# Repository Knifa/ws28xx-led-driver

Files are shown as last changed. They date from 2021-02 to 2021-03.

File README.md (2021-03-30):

# ws28xx-led-driver

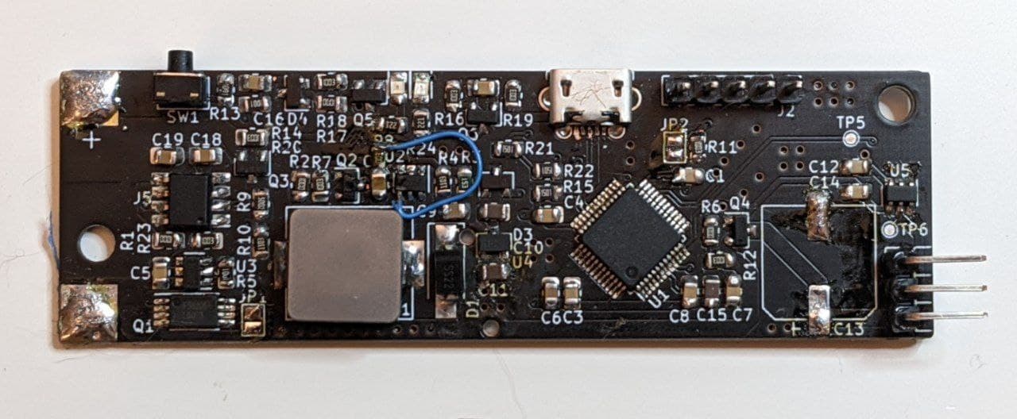
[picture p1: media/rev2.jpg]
Rev 2


This is a straightforward DIY WS28xx LED driver. It's got these features:

- STM32F103C8T6 used as the microcontroller.
- Intended to be powered by a single-cell Li-ion battery, with USB charging and
  cell protection.
- 5V 1.5Aish step-up for LED power.
- Single button for soft-power and settings.
- 0805 SMD components or thereabouts.

## License

- Firmware under [MIT License](./firmware/LICENSE.md).
- Hardware under [CC-BY-SA-4.0](./hardware/LICENSE.md).

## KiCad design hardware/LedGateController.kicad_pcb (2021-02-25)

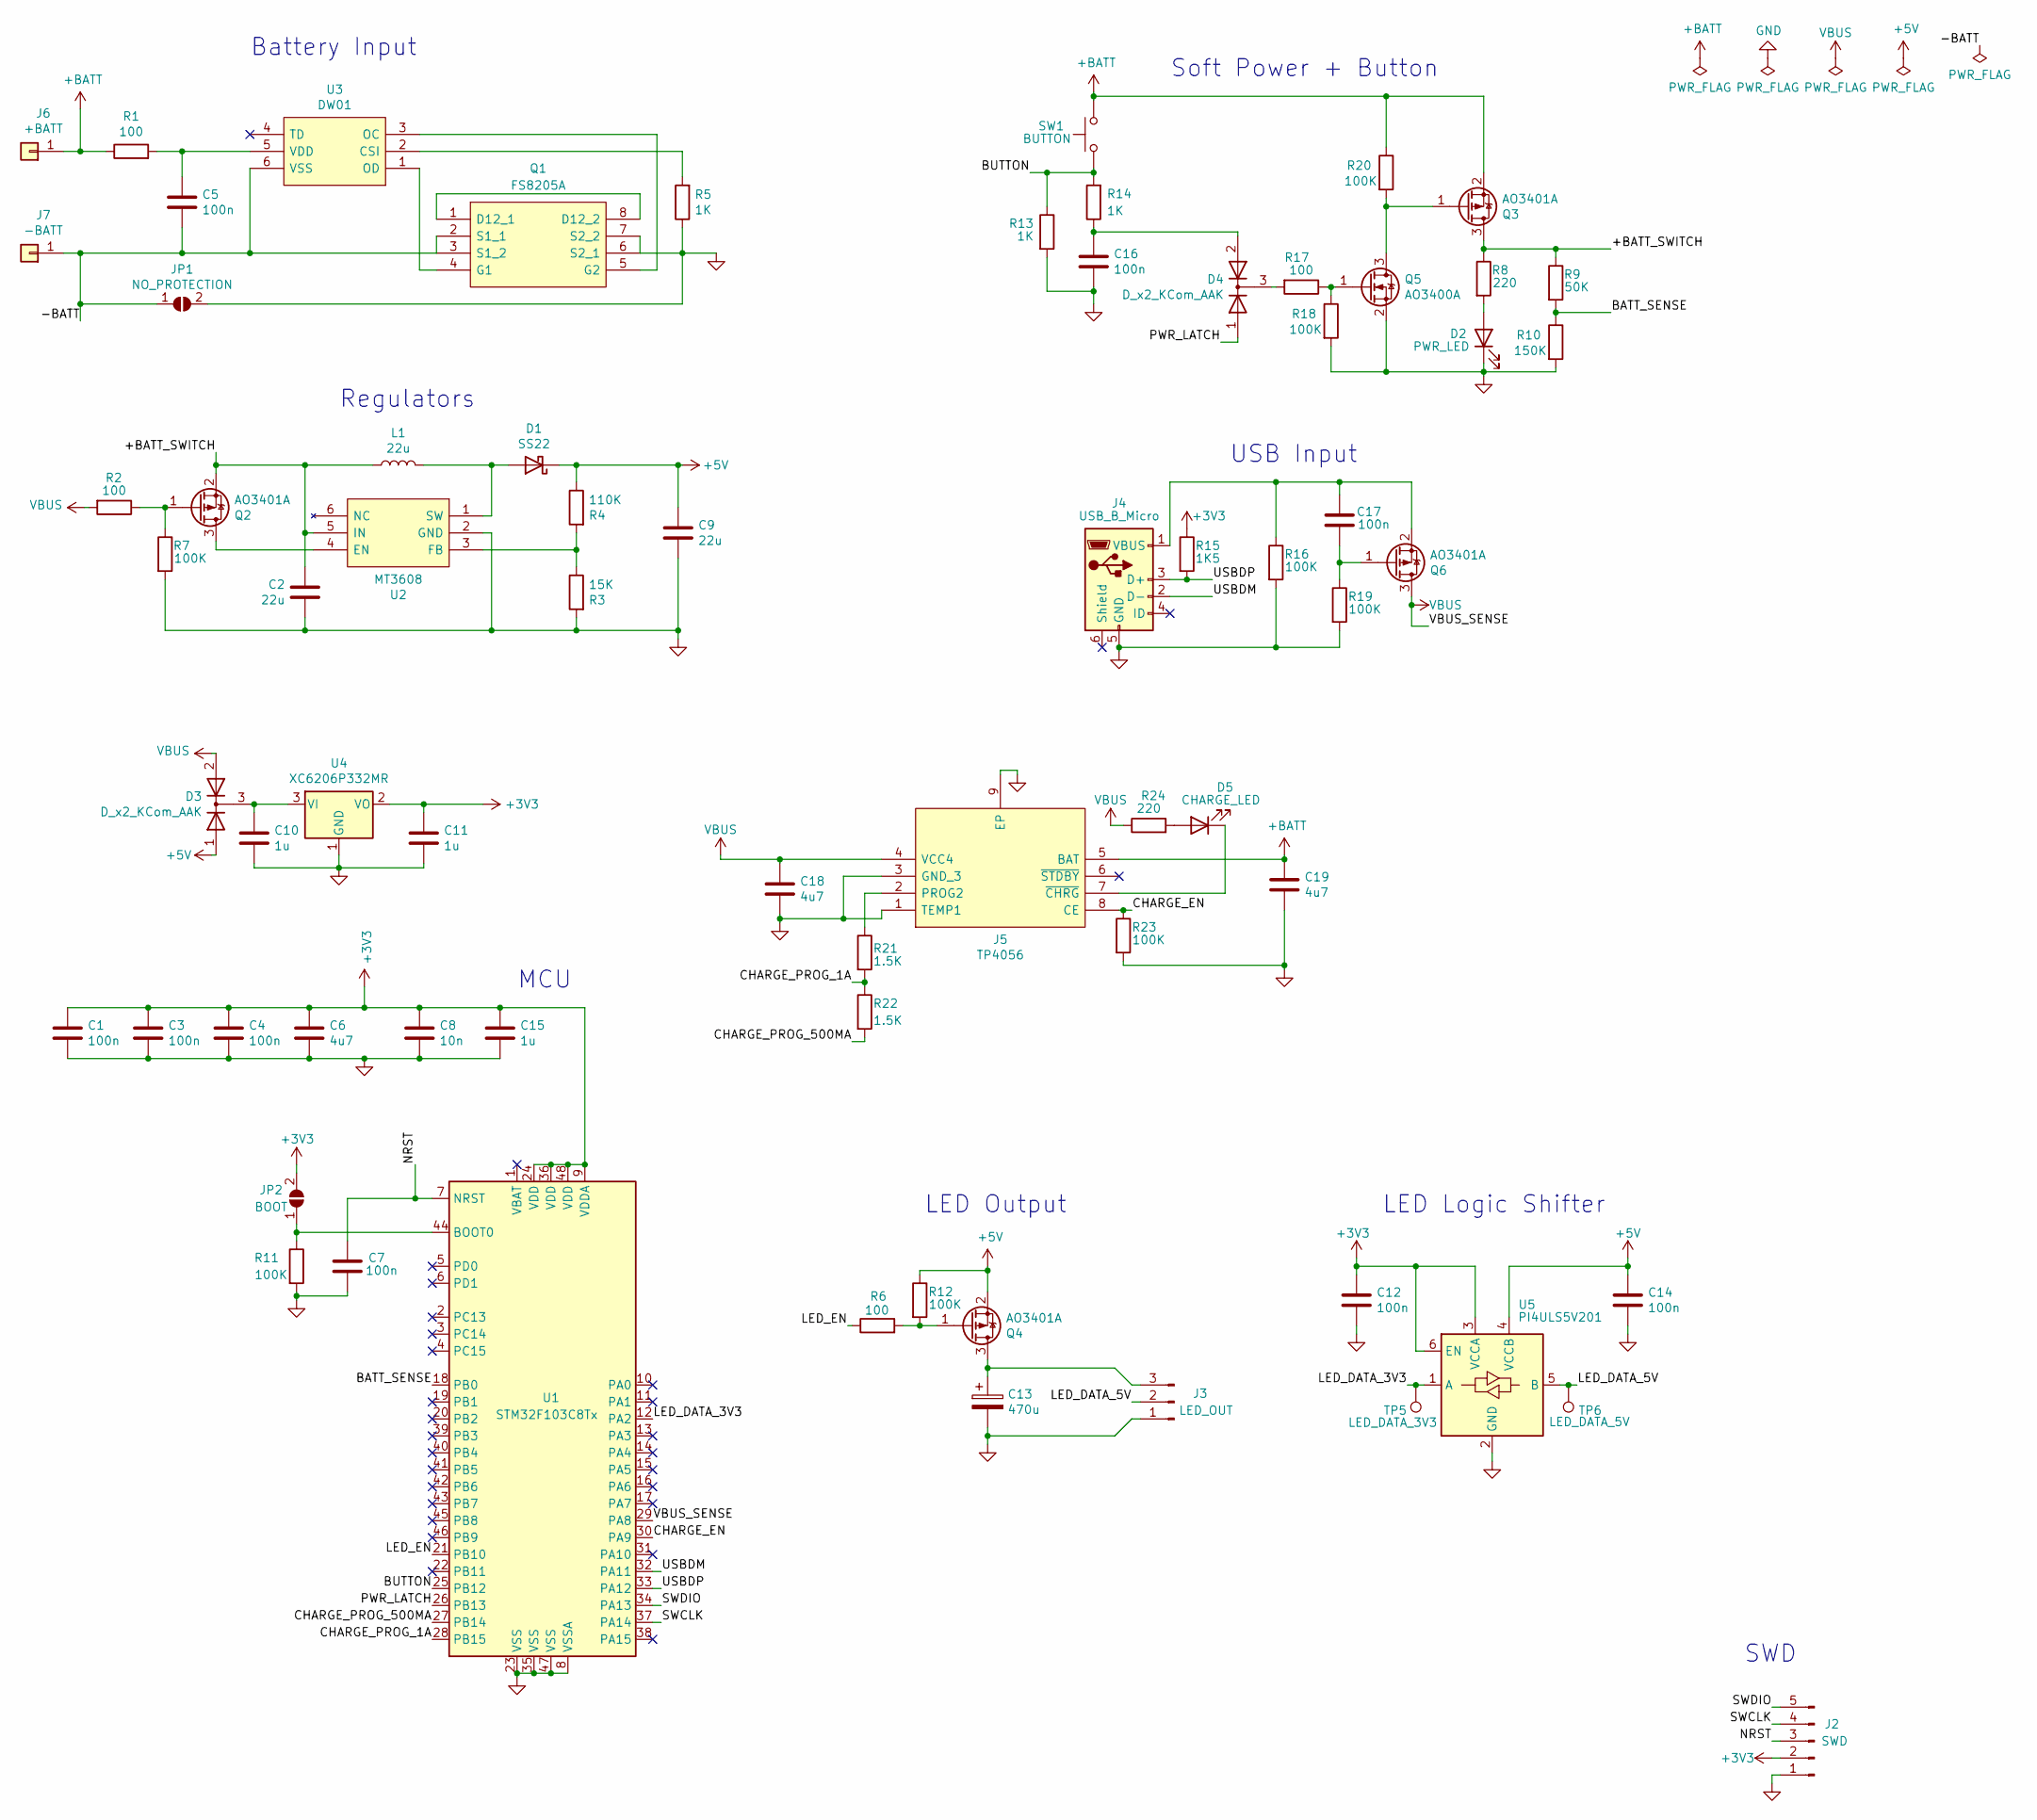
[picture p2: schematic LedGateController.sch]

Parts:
C1, C3, C4, C5, C7, C12, C14, C16, C17: 100n; C_0805_2012Metric
C2, C9: 22u; C_0805_2012Metric
C6, C18, C19: 4u7; C_0805_2012Metric
C8: 10n; C_0805_2012Metric
C10, C11, C15: 1u; C_0805_2012Metric
C13: 470u; CP_Elec_10x7.7
D1: SS22; D_SMA_Handsoldering
D2: PWR_LED; LED_0805_2012Metric
D3, D4: D_x2_KCom_AAK; SOT-23
D5: CHARGE_LED; LED_0805_2012Metric
J2: SWD; PinHeader_1x05_P2.54mm_Vertical
J3: LED_OUT; PinHeader_1x03_P2.54mm_Horizontal
J4: USB_B_Micro; U254051T4BHJ25S2S
J5: TP4056; SOIC127P600X175-9N; Manufacturer_Part_Number TP4056
J6: +BATT; Battery Pad
J7: -BATT; Battery Pad
JP1: NO_PROTECTION; SolderJumper-2_P1.3mm_Open_Pad1.0x1.5mm
JP2: BOOT; SolderJumper-2_P1.3mm_Open_Pad1.0x1.5mm
L1: 22u; YT1040-220M
Q1: FS8205A; TSSOP-8_4.4x3mm_P0.65mm; Manufacturer_Part_Number FS8205A
Q2, Q3, Q4, Q6: AO3401A; SOT-23
Q5: AO3400A; SOT-23
R1, R2, R6, R17: 100; R_0805_2012Metric
R3: 15K; R_0805_2012Metric
R4: 110K; R_0805_2012Metric
R5, R13, R14: 1K; R_0805_2012Metric
R7, R11, R12, R16, R18, R19, R20, R23: 100K; R_0805_2012Metric
R8, R24: 220; R_0805_2012Metric
R9: 50K; R_0805_2012Metric
R10: 150K; R_0805_2012Metric
R15: 1K5; R_0805_2012Metric
R21, R22: 1.5K; R_0805_2012Metric
SW1: BUTTON; TS-1009B-04326
TP5: LED_DATA_3V3; TestPoint_Pad_D1.0mm
TP6: LED_DATA_5V; TestPoint_Pad_D1.0mm
U1: STM32F103C8Tx; LQFP-48_7x7mm_P0.5mm
U2: MT3608; SOT-23-6; Manufacturer_Part_Number MT3608
U3: DW01; SOT-23-6; Manufacturer_Part_Number DW01
U4: XC6206P332MR; SOT-23
U5: PI4ULS5V201; SOT-23-6

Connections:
+3V3: C1.1, C3.1, C4.1, C6.1, C8.1, C11.1, C12.1, C15.1, J2.2, JP2.2 (B), R15.1, U1.9 (VDDA), U1.24 (VDD), U1.36 (VDD), U1.48 (VDD), U4.2 (VO), U5.3 (VCCA), U5.6 (EN)
+5V: C9.1, C14.1, D1.1 (K), D3.1 (A), Q4.2 (S), R4.1, R12.1, U5.4 (VCCB)
+BATT: C19.1, J5.5 (BAT), J6.1, Q3.2 (S), R1.1, R20.1, SW1.2; also elsewhere on the board
/+BATT_SWITCH: C2.1, L1.1, Q2.2 (S), Q3.3 (D), R8.1, R9.1, U2.5 (IN)
/-BATT: C5.2, J7.1, JP1.1 (A), Q1.2 (S1_1), Q1.3 (S1_2), U3.6 (VSS)
/BATT_SENSE: R9.2, R10.1, U1.18 (PB0)
/BUTTON: R13.1, R14.2, SW1.1, U1.25 (PB12)
/CHARGE_EN: J5.8 (CE), R23.1, U1.30 (PA9)
/CHARGE_PROG_1A: R21.2, R22.1, U1.28 (PB15)
/CHARGE_PROG_500MA: R22.2, U1.27 (PB14)
/LED_DATA_3V3: TP5.1, U1.12 (PA2), U5.1 (A)
/LED_DATA_5V: J3.2, TP6.1, U5.5 (B)
/LED_EN: R6.1, U1.21 (PB10)
/NRST: C7.2, J2.3, U1.7 (NRST)
/PWR_LATCH: D4.1 (A), U1.26 (PB13)
/SWCLK: J2.4, U1.37 (PA14)
/SWDIO: J2.5, U1.34 (PA13)
/USBDM: J4.2 (D-), U1.32 (PA11)
/USBDP: J4.3 (D+), R15.2, U1.33 (PA12)
GND: C1.2, C2.2, C3.2, C4.2, C6.2, C7.1, C8.2, C9.2, C10.2, C11.2, C12.2, C13.2, C14.2, C15.2, C16.2, C18.2, C19.2, D2.1 (K), J2.1, J3.1, J4.5 (GND), J5.1 (TEMP1), J5.3 (GND_3), J5.9 (EP), JP1.2 (B), Q1.6 (S2_1), Q1.7 (S2_2), Q5.2 (S), R3.2, R5.1, R7.2, R10.2, R11.2, R13.2, R16.2, R18.2, R19.2, R23.2, U1.8 (VSSA), U1.23 (VSS), U1.35 (VSS), U1.47 (VSS), U2.2 (GND), U4.1 (GND), U5.2 (GND)
unnamed: C5.1, R1.2, U3.5 (VDD)
unnamed: C10.1, D3.3 (K), U4.3 (VI)
unnamed: C13.1, J3.3, Q4.3 (D)
unnamed: C16.1, D4.2 (A), R14.1
unnamed: C17.1, J4.1 (VBUS), Q6.2 (S), R16.1
unnamed: C17.2, Q6.1 (G), R19.1
unnamed: D1.2 (A), L1.2, U2.1 (SW)
unnamed: D2.2 (A), R8.2
unnamed: D4.3 (K), R17.2
unnamed: D5.1 (K), J5.7 (~CHRG)
unnamed: D5.2 (A), R24.2
unnamed: J5.2 (PROG2), R21.1
unnamed: JP2.1 (A), R11.1, U1.44 (BOOT0)
unnamed: Q1.1 (D12_1), Q1.8 (D12_2)
unnamed: Q1.4 (G1), U3.1 (OD)
unnamed: Q1.5 (G2), U3.3 (OC)
unnamed: Q2.1 (G), R2.1, R7.1
unnamed: Q2.3 (D), U2.4 (EN)
unnamed: Q3.1 (G), Q5.3 (D), R20.2
unnamed: Q4.1 (G), R6.2, R12.2
unnamed: Q5.1 (G), R17.1, R18.1
unnamed: R3.1, R4.2, U2.3 (FB)
unnamed: R5.2, U3.2 (CSI)
VBUS: C18.1, D3.2 (A), J5.4 (VCC4), Q6.3 (D), R2.2, R24.1, U1.29 (PA8)

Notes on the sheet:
Regulators
MCU
SWD
Battery Input
LED Output
LED Logic Shifter
Soft Power + Button
USB Input

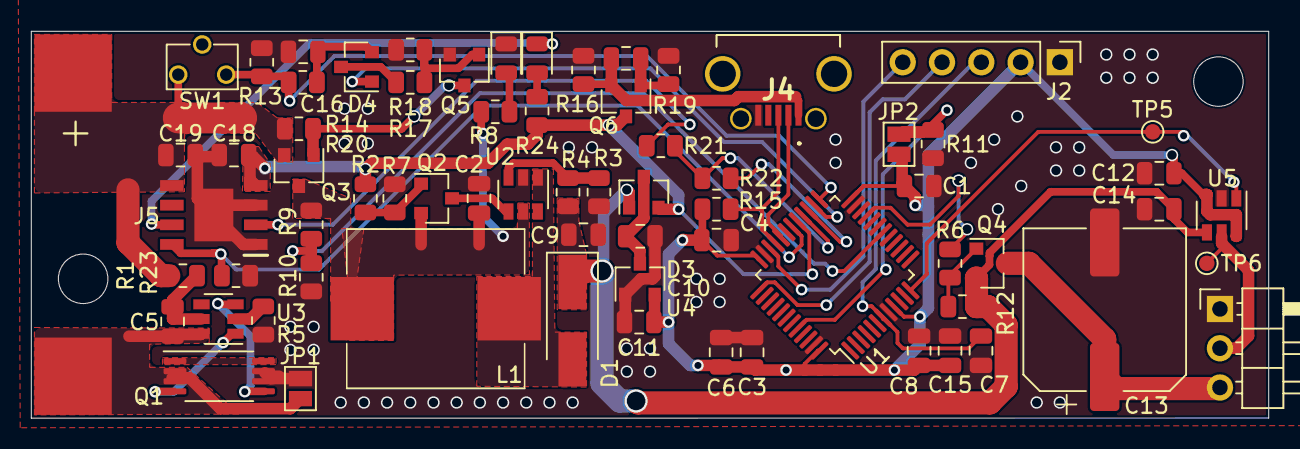
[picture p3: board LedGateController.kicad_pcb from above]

Board: 2 copper layers, 80.0 x 25.0 mm, 71 parts (0 on the bottom side), 44 nets.

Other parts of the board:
+: +BATT; Battery Pad

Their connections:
+BATT: +.1; also elsewhere on the board

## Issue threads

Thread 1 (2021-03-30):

Rev. 3 Oopsies

Knifa, 2021-03-30:
Uh oh!

- [ ] MT3608 EN needs pull-down.
- [ ] LED 5V cap needs inrush limit.
- [ ] LED 5V cap could be smaller.
- [ ] MCU needs external oscillator to reach 72MHz and stable USB.

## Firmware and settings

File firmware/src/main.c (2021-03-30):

#include "pwr.h"
#include "button.h"
#include "led.h"
#include "mode.h"
#include "stm32f1xx_ll_bus.h"
#include "stm32f1xx_ll_cortex.h"
#include "stm32f1xx_ll_dma.h"
#include "stm32f1xx_ll_exti.h"
#include "stm32f1xx_ll_gpio.h"
#include "stm32f1xx_ll_pwr.h"
#include "stm32f1xx_ll_rcc.h"
#include "stm32f1xx_ll_system.h"
#include "stm32f1xx_ll_tim.h"
#include "stm32f1xx_ll_utils.h"
#include "time.h"

#define BATTERY_CHECK_MS 5000
#define DRAW_MS (1000 / 60)

static void init_clocks();
static void check_battery();

int main()
{
  init_clocks();

  pwr_init();

  if (pwr_is_vbus_present())
  {
    pwr_shutdown();
    pwr_set_chg_enable(1);
    while (1)
    {
    }
  }

  button_init();
  led_init();

  led_set_power(1);
  check_battery();

  NVIC_SetPriority(SysTick_IRQn, 255);
  NVIC_EnableIRQ(SysTick_IRQn);
  LL_SYSTICK_EnableIT();

  while (1)
  {
  }
}

void init_clocks()
{
  LL_FLASH_SetLatency(LL_FLASH_LATENCY_1);

  LL_RCC_HSI_Enable();
  while (LL_RCC_HSI_IsReady() != 1)
  {
  };

  LL_RCC_PLL_ConfigDomain_SYS(LL_RCC_PLLSOURCE_HSI_DIV_2, LL_RCC_PLL_MUL_12);
  LL_RCC_PLL_Enable();
  while (LL_RCC_PLL_IsReady() != 1)
  {
  };

  LL_RCC_SetAHBPrescaler(LL_RCC_SYSCLK_DIV_1);
  LL_RCC_SetAPB1Prescaler(LL_RCC_APB1_DIV_2);
  LL_RCC_SetAPB2Prescaler(LL_RCC_APB2_DIV_1);
  LL_RCC_SetADCClockSource(LL_RCC_ADC_CLKSRC_PCLK2_DIV_4);

  LL_RCC_SetSysClkSource(LL_RCC_SYS_CLKSOURCE_PLL);
  while (LL_RCC_GetSysClkSource() != LL_RCC_SYS_CLKSOURCE_STATUS_PLL)
  {
  };

  LL_SetSystemCoreClock(48000000);
  LL_Init1msTick(48000000);

  LL_AHB1_GRP1_EnableClock(LL_AHB1_GRP1_PERIPH_DMA1);

  LL_APB1_GRP1_EnableClock(LL_APB1_GRP1_PERIPH_TIM2);
  LL_APB1_GRP1_EnableClock(LL_APB1_GRP1_PERIPH_TIM3);

  LL_APB2_GRP1_EnableClock(LL_APB2_GRP1_PERIPH_GPIOA);
  LL_APB2_GRP1_EnableClock(LL_APB2_GRP1_PERIPH_GPIOB);
  LL_APB2_GRP1_EnableClock(LL_APB2_GRP1_PERIPH_ADC1);
  LL_APB2_GRP1_EnableClock(LL_APB2_GRP1_PERIPH_ADC2);
}

void check_battery()
{
  uint32_t bat = pwr_get_bat_voltage();
  if (led_get_power())
  {
    if (bat < PWR_BAT_OFF_THRESHOLD)
    {
      led_set_power(0);
    }
  }
  else
  {
    if (bat >= PWR_BAT_ON_THRESHOLD)
    {
      led_set_power(1);
    }
  }
}

void SysTick_Handler()
{
  time_systick_handler();

  if (time_millis() % BATTERY_CHECK_MS == 0)
  {
    check_battery();
  }

  if (time_millis() % DRAW_MS == 0)
  {
    mode_update();
    led_update();
  }
}

void button_handler(ButtonEvent *event)
{
  static Mode last_mode;

  switch (event->type)
  {
  case (BUTTON_EVENT_HELD):
    last_mode = mode;
    mode = MODE_BATTERY;
    break;

  case (BUTTON_EVENT_HELD_RELEASE):
    mode = last_mode;
    break;

  case (BUTTON_EVENT_PRESSES):
    switch (event->presses)
    {
    case 1:
      color_i = (color_i + 1) % COLORS_LEN;
      break;

    case 2:
      mode = (mode + 1) % MODE_BATTERY;
      break;

    case 3:
      led_set_brightness((led_get_brightness() + 1) % LED_BRIGHTNESS_MAX);
      break;
    }
    break;
  }
}

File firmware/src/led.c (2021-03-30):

#include "led.h"

#include <stm32f1xx_ll_dma.h>
#include <stm32f1xx_ll_gpio.h>
#include <stm32f1xx_ll_tim.h>

#define POWER_PIN LL_GPIO_PIN_10
#define DATA_PIN LL_GPIO_PIN_2

#define LED_BPP 24

#define ARR_TX 59

#define CCR_US_PERIOD 125
#define CCR_US_0 40
#define CCR_US_1 80

#define CCR_0 (ARR_TX * CCR_US_0 / CCR_US_PERIOD)
#define CCR_1 (ARR_TX * CCR_US_1 / CCR_US_PERIOD)
#define CCR_RESET 0

#define CCR_BUFFER_LEDS_HALF 8
#define CCR_BUFFER_LEDS (CCR_BUFFER_LEDS_HALF * 2)

#define CCR_BUFFER_LEN (CCR_BUFFER_LEDS * LED_BPP)

static uint32_t rgb_buf[LED_COUNT];
static uint32_t *rgb = rgb_buf;

static uint32_t rgb_led_buf[LED_COUNT];
static uint32_t *rgb_led = rgb_led_buf;

static uint32_t rgb_offset = 0;
static uint8_t ccr_buffer[CCR_BUFFER_LEN];

static uint8_t brightness_i = 3;
static uint8_t is_powered = 0;
static uint8_t is_transmitting = 0;

static uint8_t apply_brightness(uint8_t v);
static uint8_t apply_gamma(uint8_t v);
static void fill_ccr_buffer(uint32_t ccr_led_offset, uint32_t ccr_led_count);
static void handle_dma();

void led_init()
{
  LL_GPIO_InitTypeDef gpio_init = {0};
  LL_TIM_InitTypeDef tim_init = {0};
  LL_TIM_OC_InitTypeDef tim_oc_init = {0};

  tim_init.Prescaler = 0;
  tim_init.CounterMode = LL_TIM_COUNTERMODE_UP;
  tim_init.Autoreload = ARR_TX;
  tim_init.RepetitionCounter = 0;

  LL_TIM_Init(TIM2, &tim_init);
  LL_TIM_EnableAllOutputs(TIM2);
  LL_TIM_EnableDMAReq_CC3(TIM2);

  tim_oc_init.OCMode = LL_TIM_OCMODE_PWM1;
  tim_oc_init.OCState = LL_TIM_OCSTATE_ENABLE;
  tim_oc_init.CompareValue = 0;

  LL_TIM_OC_Init(TIM2, LL_TIM_CHANNEL_CH3, &tim_oc_init);
  LL_TIM_OC_EnablePreload(TIM2, LL_TIM_CHANNEL_CH3);

  LL_DMA_SetPeriphAddress(DMA1, LL_DMA_CHANNEL_1, (uint32_t)&TIM2->CCR3);
  LL_DMA_SetChannelPriorityLevel(DMA1, LL_DMA_CHANNEL_1,
                                 LL_DMA_PRIORITY_VERYHIGH);
  LL_DMA_SetDataTransferDirection(DMA1, LL_DMA_CHANNEL_1,
                                  LL_DMA_DIRECTION_MEMORY_TO_PERIPH);
  LL_DMA_SetPeriphIncMode(DMA1, LL_DMA_CHANNEL_1, LL_DMA_PERIPH_NOINCREMENT);
  LL_DMA_SetMemoryIncMode(DMA1, LL_DMA_CHANNEL_1, LL_DMA_MEMORY_INCREMENT);
  LL_DMA_SetPeriphSize(DMA1, LL_DMA_CHANNEL_1, LL_DMA_PDATAALIGN_HALFWORD);
  LL_DMA_SetMemorySize(DMA1, LL_DMA_CHANNEL_1, LL_DMA_MDATAALIGN_BYTE);
  LL_DMA_EnableIT_TC(DMA1, LL_DMA_CHANNEL_1);
  LL_DMA_EnableIT_HT(DMA1, LL_DMA_CHANNEL_1);

  NVIC_SetPriority(DMA1_Channel1_IRQn, 0);
  NVIC_EnableIRQ(DMA1_Channel1_IRQn);

  // LED data
  gpio_init.Pin = DATA_PIN;
  gpio_init.Mode = LL_GPIO_MODE_ALTERNATE;
  gpio_init.Speed = LL_GPIO_SPEED_FREQ_HIGH;
  gpio_init.OutputType = LL_GPIO_OUTPUT_PUSHPULL;

  LL_GPIO_Init(GPIOA, &gpio_init);

  // LED power
  gpio_init.Pin = POWER_PIN;
  gpio_init.Mode = LL_GPIO_MODE_OUTPUT;
  gpio_init.Speed = LL_GPIO_SPEED_FREQ_LOW;
  gpio_init.OutputType = LL_GPIO_OUTPUT_OPENDRAIN;

  LL_GPIO_Init(GPIOB, &gpio_init);
  LL_GPIO_SetOutputPin(GPIOB, POWER_PIN);
}

void led_update()
{
  if (!is_powered)
  {
    return;
  }

  while (is_transmitting)
  {
  }
  is_transmitting = 1;

  for (uint8_t i = 0; i < LED_COUNT; i++)
  {
    uint32_t v = rgb[i];
    uint8_t r = RGB_R(v);
    uint8_t g = RGB_G(v);
    uint8_t b = RGB_B(v);

    r = apply_gamma(r);
    r = apply_brightness(r);

    g = apply_gamma(g);
    g = apply_brightness(g);

    b = apply_gamma(b);
    b = apply_brightness(b);

    rgb_led[i] = RGB_UINT(r, g, b);
  }

  rgb_offset = 0;
  fill_ccr_buffer(0, CCR_BUFFER_LEDS);
  rgb_offset += CCR_BUFFER_LEDS;

  LL_DMA_DisableChannel(DMA1, LL_DMA_CHANNEL_1);
  LL_DMA_SetMemoryAddress(DMA1, LL_DMA_CHANNEL_1, (uint32_t)ccr_buffer);
  LL_DMA_SetDataLength(DMA1, LL_DMA_CHANNEL_1, CCR_BUFFER_LEN);
  LL_DMA_SetMode(DMA1, LL_DMA_CHANNEL_1, LL_DMA_MODE_CIRCULAR);
  LL_DMA_EnableChannel(DMA1, LL_DMA_CHANNEL_1);

  LL_TIM_EnableCounter(TIM2);
}

uint8_t led_get_power() { return is_powered; }
uint8_t led_get_brightness() { return brightness_i; }

uint32_t led_get(uint16_t i) { return rgb[i]; }

void led_set(uint16_t i, uint32_t v) { rgb[i] = v; }

void led_set_rgb(uint16_t i, uint32_t r, uint32_t g, uint32_t b)
{
  if (i < 0 || i >= LED_COUNT)
  {
    return;
  }

  if (r < 0)
    r = 0;
  if (g < 0)
    g = 0;
  if (b < 0)
    b = 0;

  if (r > 255)
    r = 255;
  if (g > 255)
    g = 255;
  if (b > 255)
    b = 255;

  led_set(i, RGB_UINT(r, g, b));
}

void led_set_rgbf(uint16_t i, float r, float g, float b)
{
  if (r < 0)
    r = 0;
  if (g < 0)
    g = 0;
  if (b < 0)
    b = 0;

  if (r > 1)
    r = 1;
  if (g > 1)
    g = 1;
  if (b > 1)
    b = 1;

  led_set_rgb(i, r * 255, g * 255, b * 255);
}

void led_clear()
{
  for (uint32_t i = 0; i < LED_COUNT; i++)
  {
    led_set(i, 0);
  }
}

void led_set_brightness(uint8_t brightness)
{
  if (brightness < 0)
    brightness = 0;
  if (brightness > LED_BRIGHTNESS_MAX - 1)
    brightness = LED_BRIGHTNESS_MAX - 1;

  brightness_i = brightness;
}

void led_set_power(uint8_t state)
{
  if (state)
  {
    LL_GPIO_ResetOutputPin(GPIOB, POWER_PIN);
  }
  else
  {
    led_clear();
    led_update();

    LL_GPIO_SetOutputPin(GPIOB, POWER_PIN);
  }

  is_powered = state;
}

static uint8_t apply_brightness(uint8_t v)
{
  static uint8_t brightness_table[LED_BRIGHTNESS_MAX] = {50, 25, 12};

  return (uint16_t)v *
         brightness_table[(LED_BRIGHTNESS_MAX - 1) - brightness_i] / 255;
}

static uint8_t apply_gamma(uint8_t v)
{
  static uint8_t gamma_table[256] = {
      0, 0, 0, 0, 0, 0, 0, 0, 0, 0, 0, 0, 0, 0, 0,
      0, 0, 0, 0, 0, 0, 1, 1, 1, 1, 1, 1, 1, 1, 2,
      2, 2, 2, 2, 3, 3, 3, 3, 3, 4, 4, 4, 4, 5, 5,
      5, 5, 6, 6, 6, 7, 7, 7, 8, 8, 8, 9, 9, 9, 10,
      10, 10, 11, 11, 12, 12, 13, 13, 13, 14, 14, 15, 15, 16, 16,
      17, 17, 18, 18, 19, 19, 20, 21, 21, 22, 22, 23, 23, 24, 25,
      25, 26, 27, 27, 28, 29, 29, 30, 31, 31, 32, 33, 33, 34, 35,
      36, 36, 37, 38, 39, 40, 40, 41, 42, 43, 44, 45, 45, 46, 47,
      48, 49, 50, 51, 52, 53, 54, 55, 55, 56, 57, 58, 59, 60, 61,
      62, 63, 65, 66, 67, 68, 69, 70, 71, 72, 73, 74, 75, 77, 78,
      79, 80, 81, 82, 84, 85, 86, 87, 88, 90, 91, 92, 93, 95, 96,
      97, 99, 100, 101, 103, 104, 105, 107, 108, 109, 111, 112, 114, 115, 117,
      118, 119, 121, 122, 124, 125, 127, 128, 130, 131, 133, 135, 136, 138, 139,
      141, 142, 144, 146, 147, 149, 151, 152, 154, 156, 157, 159, 161, 162, 164,
      166, 168, 169, 171, 173, 175, 176, 178, 180, 182, 184, 186, 187, 189, 191,
      193, 195, 197, 199, 201, 203, 205, 207, 209, 211, 213, 215, 217, 219, 221,
      223, 225, 227, 229, 231, 233, 235, 237, 239, 241, 244, 246, 248, 250, 252,
      255};

  return gamma_table[v];
}
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

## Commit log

2020-03-30 Move to footprints
    [LedGateController.kicad_pcb, LedGateController.sch]
2020-04-24 nearly done
    [LedGateController.kicad_pcb, LedGateController.sch]
2020-04-28 Rev. 1 nearly ready!
    [LedGateController.kicad_pcb, LedGateController.sch]
2020-04-28 Fix inductor schematic
    [LedGateController.kicad_pcb, LedGateController.sch]
2020-07-21 Fix battery orientation
    [LedGateController.kicad_pcb]
2020-07-21 Bring in SamacSys parts used in project
    [LedGateController.kicad_pcb]
2020-07-21 Change rev. text
    [LedGateController.kicad_pcb]
2020-07-21 Tidy up some loose tracks
    [LedGateController.kicad_pcb]
2020-07-21 Remove unneeded ground vias
    [LedGateController.kicad_pcb]
2020-09-24 Update inductor footprint
2020-09-24 Update schematic
    [LedGateController.kicad_pcb, LedGateController.sch]
2021-01-07 Rewire top section
    [LedGateController.kicad_pcb, LedGateController.sch]
2021-02-07 Rev 2
    [LedGateController.kicad_pcb, LedGateController.sch]
2021-02-25 rev 2 ordered
    [LedGateController-B_Cu.gbr, LedGateController-B_Mask.gbr, LedGateController-B_SilkS.gbr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]
2021-03-30 monorepo it up
    [LedGateController-B_Cu.gbr, LedGateController-B_Mask.gbr, LedGateController-B_SilkS.gbr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]
